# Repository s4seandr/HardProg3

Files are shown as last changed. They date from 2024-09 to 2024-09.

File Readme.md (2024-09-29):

# Wetterstation mit ESP32 und RaspberryPI Zero

## 1. Einleitung und Motivation zur Wetterstation
Da Wetterdienste das aktuelle Wetter für meine Region (gefühlt) immer schlechter anzeigen und voraussagen, mich diese Daten jedoch interessieren, wollte ich mir schon länger eine Wetterstation für zuhause kaufen. Mit diesem Projekt habe ich nun die Möglichkeit, eine Wetterstation selbst umzusetzen. Dadurch werde ich nun in Zukunft selbst meine aktuellen Wetterdaten für Innen- und Außenbereich erfassen können und diese auf einem geeigneten Medium ausgeben oder auch für andere Anwendungen weiterverwenden können.

Bei meinem Projekt nutze ich zwei ESP32, die mit jeweils einem BME280 und einem Lichtsensor ausgestattet sind. Ein ESP-Modul soll mit Hilfe eines Batteriemoduls die Wetterdaten außen messen, während der zweite ESP die Werte in der Wohnung misst. Die gemessenen Werte sollen anschließend über das Wifi an den RaspberryPi Zero übermittelt werden, der mit Hilfe einer RGB-LED-Matrix (64x32) die Daten ausgibt.

## 2. Beschreibung der genutzten Hardware-Komponenten
- **2x ESP32 (12,99€)** <br>
        Bei den genutzten ESPs handelt es sich um ESP32 Typ C NodeMCU Entwicklungsboards. Jedes Board ist mit einem ESP-WROOM-32 Modul ausgestattet, das einen leistungsstarken Mikrocontroller mit Dual-Core-Prozessoren und integrierter 2.4GHz Dual-Mode WiFi und Bluetooth-Funktionalität bietet. Durch den Deep-            Sleep-Modus eignet sich der ESP32 besonders gut für dieses Projekt, da das Outdoor-Modul mit einem Akku betrieben werden muss.
          <br>
          
        <br clear="left">
        
- **2x BME280 (15,99€)** <br>
         Der BME280 ist ein Sensor-Modul, dass die Temperatur, Luftfeuchtigkeit und Luftdruck messen kann. Sie nutzen eine Spannung von 5V und sind mit einem IIC/I2C Interface ausgestattet, was sie kompatibel mit Arduino und Raspberry Pi macht. Ein Nachteil des BME280 ist jedoch, dass er sich beim Dauereinstatz         erwärmt, was zu falschen Messergebnissen führen kann. Da die Daten jedoch nur alle 10 Minuten aktualiesert werden, ist das für dieses Projekt kein Problem. 
        <br>
          
        <br clear="left">

- **2x Lichtsensor (5,49€)** <br>
         Als Lichtsensoren wurden KY-018 LDR (Light Dependent Resistor) Lichtsensor-Module genutzt. Diese Sensoren messen die Helligkeit des Umgebungslichts und bestehen aus einer Fotodiode, die an einen Widerstand gekoppelt ist. Der Widerstandswert des Sensors ändert sich je nach Lichtintensität.
         <br>
          
        <br clear="left">
  
- **14x Jumper Cable (10cm, 8x Male-Female, 6x Female-Female) (6,99€)** <br>
          Die Jumper Cables werden benötigt, um die Sensoren mit den ESP32 zu verbinden.
          <br>
          
        <br clear="left">

- **1x Batteriemodul mit 2x wiederaufladbaren Akkus (9,99€ + 26,99€)** <br>
           Das Batteriemodul hat Platz für 2 Batterien und verfügt über einen integrierten Überspannschutz und hat im Gegensatz zu hat mehrere nutzbare Ausgänge und im Gegensatz zu den meisten herkömmlichen Powerbanks die Möglichkeit ein automatisches Abstellen des Stromflusses bei zu geringem Verbrauch zu verhindern.
           Da bei diesem Projekt der Deep-Sleep-Modus des ESP32 genutzt wird, ist das unerlässlich.
           <br>
          
        <br clear="left">
          Die genutzten Akkus sind 3.7V NiMH Akkus mit einer Kapazität von 3000mAh. Sie haben das Format 18650.
           <br>
          
        <br clear="left">

- **1x RaspberryPI Zero (WH) (23,49€)** <br>
          Der Raspberry Pi Zero WH ist eine kompakte und kostengünstige Version des Raspberry Pi, die mit einer vorinstallierten GPIO-Stiftleiste geliefert wird. Dies erleichtert die Verbindung mit anderen Geräten und Sensoren, ohne dass Löten erforderlich ist.
          <br>
          
        <br clear="left">

- **1x RGB-Matrix-Bonnet für einen RaspberryPI (25,99€)** <br>
          Das Adafruit RGB Matrix Bonnet ist ein Erweiterungsmodul für den Raspberry Pi, das die Steuerung von RGB-LED-Matrizen vereinfacht. Es wird direkt auf den Raspberry Pi gesteckt und ermöglicht die einfache Ansteuerung von RGB-Matrizen.
          <br>
          
        <br clear="left">

- **1x RGB-Matrix (64x32) (29,99€)** <br>
          Die Matrix besteht aus 2048 RGB-LEDs und ermöglicht die Darstellung von Texten, farbigen Bildern und Animationen.
          <br>
          
        <br clear="left">
  
- **1x 3d-gedruckte Hülle für den Outdoor-Sensor (1 Kasten Bayreuther Bier)** <br>
        Als Druckmaterial wurde ASA verwendet, da dieses beständiger als PLA ist und zusätzlich auch UV-beständig ist. Dadurch eignet es sich viel besser zum Outdoor-Einsatz, ist jedoch auch schwerer zu drucken.
        
## 3. Implementierung
Die Implementierung setzt sich aus 2 Teilen zusammen: Den beiden ESP32-Sensormodulen und der Basisstation mit einem lokalen Server und Ausgabe der Daten auf der RGB-Matrix auf dem Raspberry PI Zero.
Im Folgenden werde ich nun auf den Aufbau der Hardware eingehen und anschließend den erstellten Code erklären.

### 3.1 Aufbau der Komponenten
#### 3.1.1 ESP32
Für den Lichtsensor habe ich die PINs VIN, GND und D34 genutzt. VIN und GND werden für die Stromzufuhr vom ESP32 zum Lichtsensor benötigt und der PIN 34 ist ein Einganspin, was bedeutet, dass dieser PIN nur Signale empfangen kann. Zusätzlich besitzt er keine Pull-Up oder Pull-Down Widerstand, weshalb er sich auch gut für analoge Signale eignet. Die Female-Female Jumper Cable können einfach an den Sensor angeschlossen werden.
Lichtsensor

Für den BME280 habe ich die PINs 3V3, GND, D21 und D22 genutzt. Ebenfalls wie beim Lichtsensor werden 3V3 und GND für die Stromzufuhr zum Messsensor benötigt. Die weiteren genutzten PINs 21 und 22 sind die Standard-PINs für das I2C-Protokoll zur Datenübertragung. D21 muss für SDA (Serial Data) genutzt werden und D22 für SCL (Serial Clock). Die Male-Female Jumper Cable müssen mit dem Sensor verlötet werden, damit der Kontakt gewährleistet werden kann.
BMEsensor

#### 3.1.2 Raspberry PI Zero (WH)
Auf den Raspberry PI Zero (WH) muss das RGB-Matrix-Bonnet angeschlossen werden. Hierfür müssen der Bonnet entsprechend auf die Header gesetzt werden. 
RPI_Bonnet

Anschließend muss das Datenkabel der RGB-Matrix mit dem IDC-Anschluss auf dem RGB-Matrix-Bonnet verbunden werden. Hierbei ist zu beachten, dass die Ausrichtung der Pins korrekt ist. Dann muss das Stromkabel der RGB-Matrix an die Stromanschlüsse auf dem RGB-Matrix-Bonnet angeschlossen werden. Dabei ist auf die Polarität des Stromanschluss zu achten.
RPI_Bonnet_Matrix

### 3.2 3D-Druck des Outdoor-ESP32-Moduls
In dem Ordner "3D-Drucker_Vorlagen" ist die für dieses Projekt erstellte Hülle für das ESP32-Outdoor-Modul zu finden. Die Hülle besteht aus Ober- und Unterseite und enthalten. An der Oberseite werden der ESP32 sowie die Sensoren befestigt, welche an der Seite des Gehäuses eine kleine Öffnung haben, damit sie die Außenwerte messen können.
<p align="center">
  
  
</p>
Wie auf den Abbildungen zu erkennen ist, hat der Lichtsensor extra eine Aussparung, in die der Sensor eingesetzt werden kann und für den BME280 wurde eine extra Überdachung erstellt, um diesen vor Wasserschäden zu schützen. <br>

In der Unterseite wird das Batteriemodul eingesetzt. Wie an der seitlichen Ansicht zu sehen ist, wurden kleine Löcher in die Seite der Hülle eingesetzt, damit bei dem Modul keine Überhitzung im Sommer zu befürchten ist. Sowohl das Batteriemodul als auch das ESP32 werden mit 2,5mm dicken und 6mm langen Zylinderschrauben befestigt. Ebenso werden die beiden Seiten der Hülle mit 2,5mm dicken jedoch 20mm langen Zylinderschrauben miteinander verschlossen. 
<p align="center">
  
  
</p>
Im zu Beginn genannten Ordner sind für die Unter- und Oberseite der Hülle zwei Dateien enthalten. Die STL-Datei enthält die 3D-Daten, die mit einem CAD-Programm nach den eigenen Bedingungen angepasst werden kann. Die GCODE-Datei ist aus der STL-Datei durch ein Slicer-Programm erstellt worden und enthält die Anweisungen für den 3D-Drucker, wie z.B. die Druckbahnen, Geschwindigkeit und Temperatur. Da es sich bei dem Modul um ein Outdoor-Modul handelt, sollte ASA als Material verwendet werden, da dieses weitaus Wetterbeständiges ist als das öfters genutzte Material PLA.

### 3.3 Anmerkungen zum Code
#### 3.3.1 ESP32
Für das Modul (ESP32WeatherStation) habe ich unter anderem die folgenden Bibliotheken genutzt: 
- **WiFi.h:** zum Erstellen einer W-Lan-Verbindung
- **HTTPClient.h** zum Erstellen der HTTP-Anfragen
- **Adafruit_BME280.h** zum Auslesen der Werte des BME280 <br>

Für den Code müssen noch WLAN-SSID und WLAN-Passwort im Code hinterlegt werden. Neben den WLAN-Zugangsdaten müssen/sollten auch noch User und Passwort für den HTTP-Request abgesendet werden.
Anschließend wird vom ESP32 die Verbindung mit dem WLAN gestartet und so lange gewartet, bis die Verbindung hergestellt wurde. Nachdem dann geprüft wurde, ob die Sensoren vorhanden sind und die Daten ermittelt wurden, erstellt der ESP32 einen HTTP-Request und sendet die Daten an den Server. Neben den Sensordaten, übermittelt der ESP32 auch, ob es sich um den "ESP32_indoor" oder "ESP32_outdoor" handelt, so kann der Server später entscheiden, woher die Daten kommen.
Nachdem ein Responsecode erhalten wurde, geht der ESP32 für 10 Minuten in den Deep Sleep. Dieser sorgt dafür, dass der ESP32 in dieser Zeit nur eine sehr geringe Menge an Strom verbraucht und statt nur einigen Tagen einige Monate arbeiten kann, ohne dass die Akkus gewechselt werden müssen.
Da der ESP in den Deep Sleep Modus wechselt, ist kein Code im Loop, weil der Setup bei jedem Durchlauf als Loop genutzt wird und der Code dadurch auch nie in den Loop geraten könnte.

#### 3.3.2 Raspberry PI Zero (WH)
Für die Implementierung des Codes wird das Github-Repository von RPI-RGB-LED-Matrix von H. Zeller genutzt (https://github.com/hzeller/rpi-rgb-led-matrix). Unter dem Pfad "rpi-rgb-led-matrix/bindings/python/samples/" habe ich dann die Python-Datei "server.py" erstellt, die die Daten der ESP32-Module empfängt, verarbeitet und auf der RGB-Matrix ausgibt.
Die wichtigsten, in diesem Code verwendeten Bibliotheken sind:
- **Flask:** zum Erstellen des Webservers, der HTTP-Anfrage empfängt
- **RGBMatrix:** zum Steuern der RGB-Matrix
- **time & threading:** zum Verwalten der Zeit und zum regelmäßigen Aktualisieren der Anzeige <br>

Die Flask-POST-Route "/data" empfängt die Daten von den ESP32-Geräten. Zu Beginn wird geprüft, ob username und password richtig sind. und die Werte aus dem Request in passenden Variablen gespeichert. Anschließend werden die Daten analysiert um zu prüfen, ob es wahrscheinlich regnet oder nicht. Bei Regen hat man eine hohe Luftfeuchtigkeit sowie einen geringen Luftdruck. Daher habe ich mich dazu entschieden, die Kriterien für Regen auf humidity > 80 und pressure < 1009 zu setzen. Ansonsten wird der Wert "No Rain" vergeben. Wenn das ESP32 ein "ESP32_indoor" ist, werden anschließend die Daten von indoor_data upgedated, wenn der ESP32 ein "ESP32_outdoor" ist, werden die Werte von outdoor_data upgedated. indoor_data und outdoor_data sind globale Variablen, die die Daten des Indoor bzw. Outdoor Gerätes speichert. <br>
In der folgenden Funktion namens "update_display()" werden die grafischen Elemente erstellt und auf der RGB-Matrix angezeigt. Die Anzeige wechselt alle 30 Sekunden zwischen der Anzeige der Indoor- oder Outdoor-Werte. Hierbei wird Threading verwendet, um die Anzeige regelmäßig zu aktualisieren, ohne den Hauptthread zu blockieren. Dadurch kann der Server weiterhin Anfragen empfangen und verarbeiten, während die Anzeige im Hintergrund aktualisiert wird.

## 4. Fazit
Wie in der folgenden Abbildung zu sehen ist, funktioniert das Modul wie gewünscht: <br>
Matrix
Die Ergebnisse der Sensormessungen werden erfolgreich an den Server auf dem RaspberryPI übertragen und anschließend von diesem auf der RGB-Matrix ausgegeben. Konkret wird der Ursprung der Daten (Indoor/Outdoor), die Temperatur, die Luftfeuchtigkeit sowie eventueller Regenfall und die Tageszeit anhand der Lichteinstrahlung angezeigt. Somit ist das Projekt insgesamt gelungen, da die vorab definierten Ziele erreicht wurden. <br>
Jedoch gilt noch zu prüfen, wie reliabel der Regenfall ermittelt wird. Im Falle einer mangelnden Reliabilität dieser Messungen könnte perspektivisch eine Anpassung der Werte oder das Hinzufügen weiterer Sensoren hilfreich sein. Beispiele für weitere interessante Sensoren wären Luftpartikelsensoren, die auch hilfreiche Daten für Allergiker liefern, oder auch ein CO2-Sensor, welcher die CO2-Konzentration in der Luft ermittelt.

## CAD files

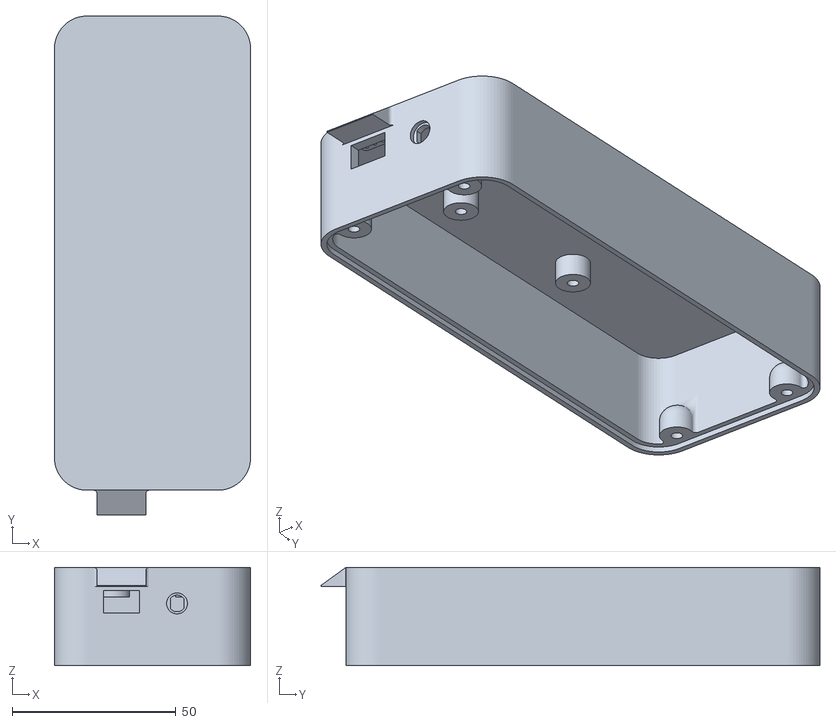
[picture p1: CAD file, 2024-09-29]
3D-Drucker_Vorlagen/Oberseite/Projekt_Oberseite.stl
60.0 x 152.6 x 30.0

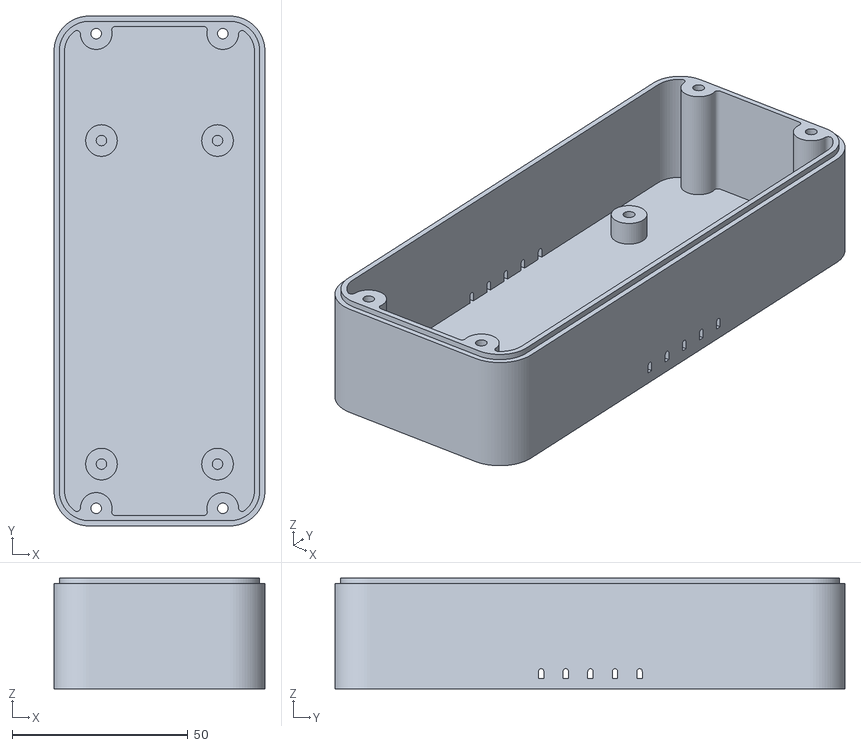
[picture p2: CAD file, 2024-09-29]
3D-Drucker_Vorlagen/Unterseite/Projekt_Unterseite.stl
60.0 x 145.0 x 31.5

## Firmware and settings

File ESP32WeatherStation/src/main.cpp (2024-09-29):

#include <Arduino.h>
#include <WiFi.h>
#include <HTTPClient.h>
#include <Wire.h>
#include <Adafruit_Sensor.h>
#include <Adafruit_BME280.h>

//define WIFI
#define WIFI_SSID "WLAN-123"
#define WIFI_PASSWORD "0123456789"

//define pins
#define LDRPIN 34
#define SEALEVELPRESSURE_HPA (1013.25)

// BME280 object
Adafruit_BME280 bme;

// Unique device ID
#define DEVICE_ID "ESP32_indoor"

void setup() {
  pinMode(LED_BUILTIN, OUTPUT);
  // put your setup code here, to run once:
  Serial.begin(921600);
  WiFi.begin(WIFI_SSID, WIFI_PASSWORD);
  digitalWrite(LED_BUILTIN, HIGH);
  Serial.println("");
  while (WiFi.status() != WL_CONNECTED)
  {
    delay(1000);
    Serial.print(".");
  }
  Serial.println("");
  Serial.println("WiFi connected!");

  // Initialize BME280 sensor
  if (!bme.begin(0x76)) {
    Serial.println("Could not find a valid BME280 sensor, check wiring!");
    while (1);
  }

  // Read LDR sensor values
  int lightvalue = analogRead(LDRPIN);

  // Read BME280 sensor values
  float temperature = bme.readTemperature();
  float pressure = bme.readPressure() / 100.0F;
  float humidity = bme.readHumidity();

  // Send data to Raspberry Pi
  if (WiFi.status() == WL_CONNECTED) {
    HTTPClient http;
    http.begin("http://192.168.2.192:5000/data");                         //ID of the RaspberryPI
    http.addHeader("Content-Type", "application/x-www-form-urlencoded");
    http.setAuthorization("admin", "20Wetterstation24");                  //Login to the RaspberryPI server

    String httpRequestData = "device_id=" + String(DEVICE_ID)
                           + "&temperature=" + String(temperature)
                           + "&pressure=" + String(pressure)
                           + "&humidity=" + String(humidity)
                           + "&lightvalue=" + String(lightvalue);

    int httpResponseCode = http.POST(httpRequestData);

    if (httpResponseCode > 0) {
      String response = http.getString();
      Serial.println(httpResponseCode);
      Serial.println(response);
    } else {
      Serial.print("Error on sending POST: ");
      Serial.println(httpResponseCode);
    }

    http.end();
  }

  //deep sleep 600s / 10min
  esp_sleep_enable_timer_wakeup(600000000);
  esp_deep_sleep_start();
}

void loop() {
  //empty because of deep sleep
}
